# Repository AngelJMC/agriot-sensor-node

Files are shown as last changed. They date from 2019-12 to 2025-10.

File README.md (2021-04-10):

# AGRIOT LoraWAN sensor node




The aim of this project is to provide an Open Source hardware/software platform for the rapid and low-cost development of LoRaWAN sensor nodes. It consists of an [Arduino Pro Mini][4] module, a LoRa [RMF95W][5] communications module, a Buck DC-DC converter and a few components to simplify connection to different sensors.

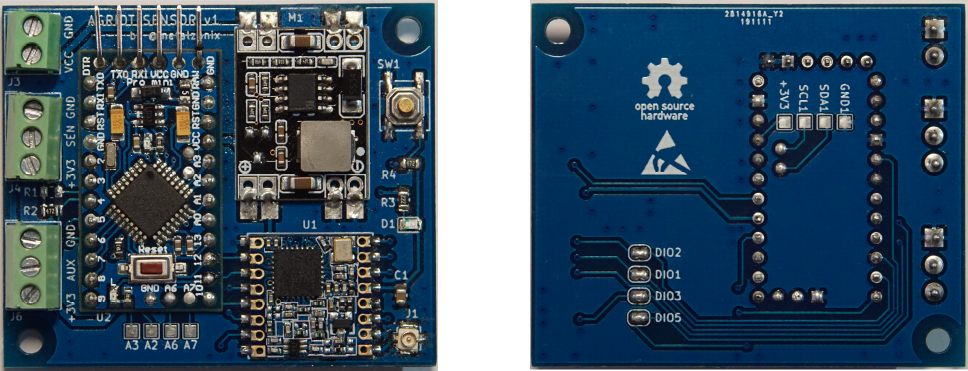
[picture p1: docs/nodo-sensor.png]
MarineGEO circle logo


## Table of contents
- [AGRIOT LoraWAN sensor Node](#agriot-lorawan-sensor-node)
  - [General info](#general-info)
  - [Table of contents](#table-of-contents)
  - [Features](#features)
    - [Hardware](#hardware)
    - [LoRaWAN Features](#lorawan-features)
    - [List of supported sensors](#list-of-supported-sensors)
  - [Get the source code](#get-the-source-code)
    - [Directory Structure](#directory-structure)
  - [Firmware](#firmware)
    - [How to add new sensor support](#how-to-add-new-sensor-support)
  - [Command Line Interface](#command-line-interface)
    - [Commands](#commands)
  - [Connect your Device to LoRaWAN - The Things Network.](#connect-your-device-to-lorawan---the-things-network)
    - [Get your Device EUI](#get-your-device-eui)
    - [Activate your Device](#activate-your-device)
  - [Hardware](#hardware-1)
    - [PCB BOM](#pcb-bom)
  - [Node Examples](#node-examples)

## Features
### Hardware
 * 5-24v Power supply through a screw terminal block.
 * 2 GPIOS accessible from screw terminal blocks, one of them with interrupt.
 * 1 IC2 interface in the botton layer, with soldering pad.
 * 4 Analog inputs in the top layer, with soldering pad.
 * A switch to force the sending of LoRaWAN messages.
### LoRaWAN Features
* [OTAA activation][7]. It is not necessary to add the OTAA activation keys in the code. They are stored in the EEPROM and the configuration is done from the serial port. 
* [Adaptative Data Rate][6] according to the SNR of periodical downlink messages.
* Using [Arduino-LMIC lowpower library][8], a modified version of Arduino-LMIC to work with the low-power modes of the Atmega328P microcontroller.
### List of supported sensors
* DHT series of low-cost temperature/humidity sensors.
* DS18S20, DS18B20, DS1822 temperature sensor.
* GPS with NMEA Standar.
* ADC121 Analog-to-digital converter with I2C interface.
    
## Get the source code
Download repository and update submodules:

```
$ git clone https://github.com/AngelJMC/agriot-sensor-node.git
$ cd agriot-sensor-node
$ git submodule update --init --recursive
```

### Directory Structure

    .
    ├── docs          # Documentation files
    ├── firmware      # FW source code (Visual Studio Code)
    ├── hardware      # HW design files (Kicad)

## Firmware
If you want to modify the source code or program your devices, it is highly recommended to use [Visual Studio Code][2] and the [Platformio][3] plugin. Just open the "firmware" directory with Visual Studio Code and the whole project will be ready for use.
### How to add new sensor support

You must create a new .cpp file in which you implement the communication routines with the sensor. If you use the following scheme you will only have to add the communication with the sensor.  The sensors_update() function is executed periodically and once the sensor acquisition is finished the data is sent by the LoRaWAN communication layer.

~~~
#ifdef SENS_SENSORNAME
#include "protocol.h"
#include "sensors.h"
#include <CayenneLPP.h>

/* Schedule sensore measurement every this senconds */
#define SENSOR_INTERVAL (5*60) //seconds

static osjob_t sensjob;
CayenneLPP lpp(51);

static void sensors_update( osjob_t* j ) {
    os_avoidSleep();

    /*TO-BE Implemented -- Read sensor*/
    float t = readYourSensor();

    /* Update Data Frame using Cayennne Library */
    lpp.reset();
    lpp.addTemperature(1, t); /*Change according your sensor*/
    protocol_updateDataFrame( lpp.getBuffer(), lpp.getSize() );

    /* Schedule next sensor reading*/
    os_setTimedCallback( &sensjob, os_getTime() + sec2osticks(SENSOR_INTERVAL), sensors_update );
    Serial.flush();
    os_acceptSleep();
}

void sensors_init( ) {

    /*TO-BE Implemented -- Init sensor*/
    initYourSensor();

    /*Schedule the first sensor reading*/
    os_setTimedCallback(&sensjob, os_getTime() + sec2osticks(10), sensors_update);
}

#endif

~~~

To compile the code for this new sensor, you will have to add to the platformio.ini configuration file a new [build environment][1].

~~~
[env:pro8MHzatmega328_SENSORNAME]
platform = atmelavr
board = pro8MHzatmega328
framework = arduino
build_flags = -DSENS_SENSORNAME
~~~

Now you will be able to select the build environment from the Visual Studio Code.

## Command Line Interface

The device configuration is done through the command line interface (CLI) implemented in the device.

First, connect your device to the Arduino Serial Monitor over USB. Since the Arduino Pro Mini does not have an on-board FTDI chip, you will need to use a USB-TTL adapter. Set the baud rate to 9600 and open the serial port to establish connection. IMPORTANT: To reduce the device power consumption, the serial interface is only available for 10 minutes after the device power-up.

### Commands

Command ID| Type   | Description 
:--------:|--------|:----------
  D       | R      |  DEVEUI -  Unique device identifier.
  E       | R/W    |  APPEUI -  Unique identifier of the application.    
  K       | R/W    |  APPKEY -  Used in OTAA to generate session keys. 

## Connect your Device to LoRaWAN - The Things Network.

To use the default Over The Air Activation (OTAA) you will need to register your device with its Device EUI

### Get your Device EUI

The Device EUI is a unique address provided by the Atmega328P microcontroller. To retrieve this, type in the serial console:

> D    

Go to The Things Network and open the application to which you wish to add a device and click register device.
        
  * For Device ID, choose a - for this application - unique ID of lower case, alphanumeric characters and nonconsecutive - and _.
  * For Device EUI, copy-paste the one you retrieved from your device.
  * Leave the App Key to be generated.
  * For App EUI, select the generated EUI from the list.

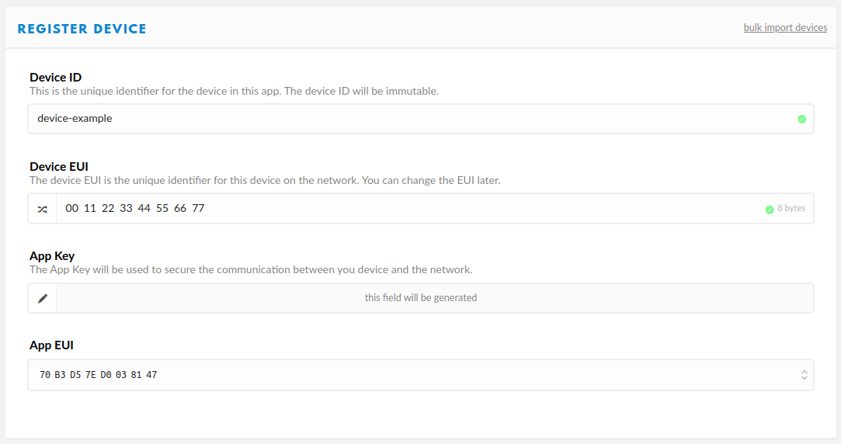
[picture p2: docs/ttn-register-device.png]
TTN Register Device


### Activate your Device

Now that we have registered the device, we can activate the connection from our device itself. Activation means that the device will use the generated App Key to negotiate session keys for further communication. 

Go to Device Overview and copy the 8-byte Application EUI. Now, you have to send the "E" command with the value obtained through the serial port of the device:

> E:70B3D57ED0038147

Repeat the same process to send the 16 byte Application key:

> K:7B4F7BC85D064898DB39214D7607440E

Now, restart the device and it will automatically register to the network.

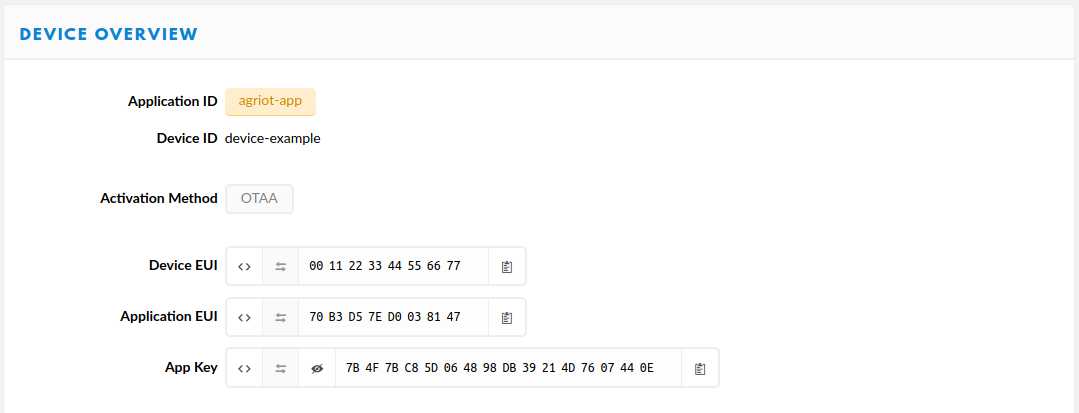
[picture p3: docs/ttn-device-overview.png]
TTN Device Overview


Session keys are not stored in non-volatile memory so they are renegotiated each time the device is powered on. This behavior is not the most appropriate, and will be reviewed in future versions.

## Hardware

Getting the gerbers for PCB fabrication [here]([hardware/gerbers](https://github.com/AngelJMC/agriot-sensor-node/tree/master/hardware/gerbers)).

### PCB BOM

| Name  | Anmount | Description |
| --- | --- | --- |
| [Arduino Pro Mini][20] | 1  | Pro Mini Armega328P 3,3V 8MHz|
| [RFM95W][21] | 1  | RFM95W 868-915MHz LoRa SX1276 transceiver |
| [DC-DC Buck][22] | 1  | 3.3V Fixed output, Input 5v-24v |
| Resistor 2.2k | 1  | 2.2K SMD resistor 0805|
| Resistor 4.7k | 3  | 4.7K SMD resistor 0805|
| Capacitor 4.7 uF/6.3 v | 1  | 4.7 uF SMD capacitor 0805 |
| SMD LED | 1  | LED SMD 0850 |
| [Switch DIP][3] | 1  | Switch 4 PIN Metal SMD  |
| [Screw Terminal 01x03][24] | 2  | 3P - Pitch 3.5/3.96mm Screw PCB Terminal Block Connector |
| [Screw Terminal 01x02][24] | 1  | 2P - Pitch 3.5/3.96mm Screw PCB Terminal Block Connector |
| [Connector U.FL-R-SMT ][25] | 1  |  Connector U.FL-R-SMT |
| [Antenna 3dbi RP-SMA][26] | 1  |  Antenna 3dbi RP-SMA Connector + 21cm SMA Male/u.FL Pigtail Cable |

[20]:https://es.aliexpress.com/item/32341751484.html?spm=a2g0s.9042311.0.0.274263c0KXTWNh
[21]:https://es.aliexpress.com/item/32811523237.html?spm=a2g0s.9042311.0.0.274263c0h3imgq
[22]:https://es.aliexpress.com/item/32742116421.html?spm=a2g0s.9042311.0.0.274263c0h3imgq
[23]:https://www.aliexpress.com/item/32989610390.html?spm=a2g0s.9042311.0.0.274263c02c3pDo
[24]:https://es.aliexpress.com/item/32868442939.html?spm=a2g0s.9042311.0.0.274263c0HmLjas
[25]:https://es.aliexpress.com/item/32833564737.html?spm=a2g0s.9042311.0.0.274263c0HmLjas
[26]:https://www.aliexpress.com/item/32977287261.html?spm=a2g0s.9042311.0.0.274263c0KXTWNh

## Node Examples
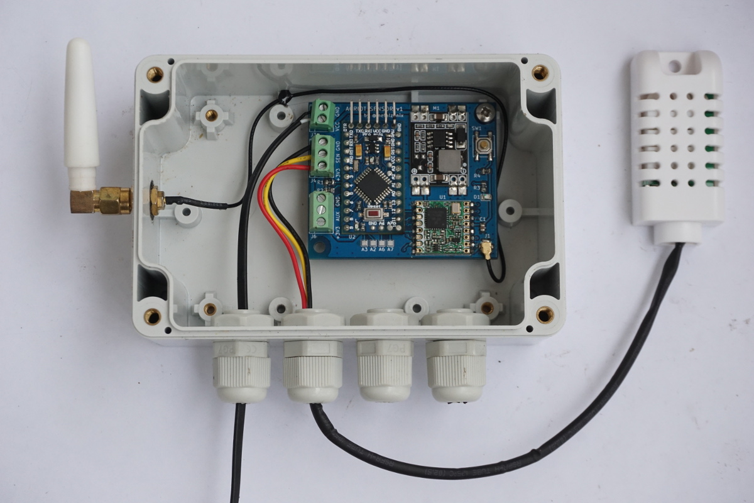
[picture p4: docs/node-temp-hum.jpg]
Sensor node example

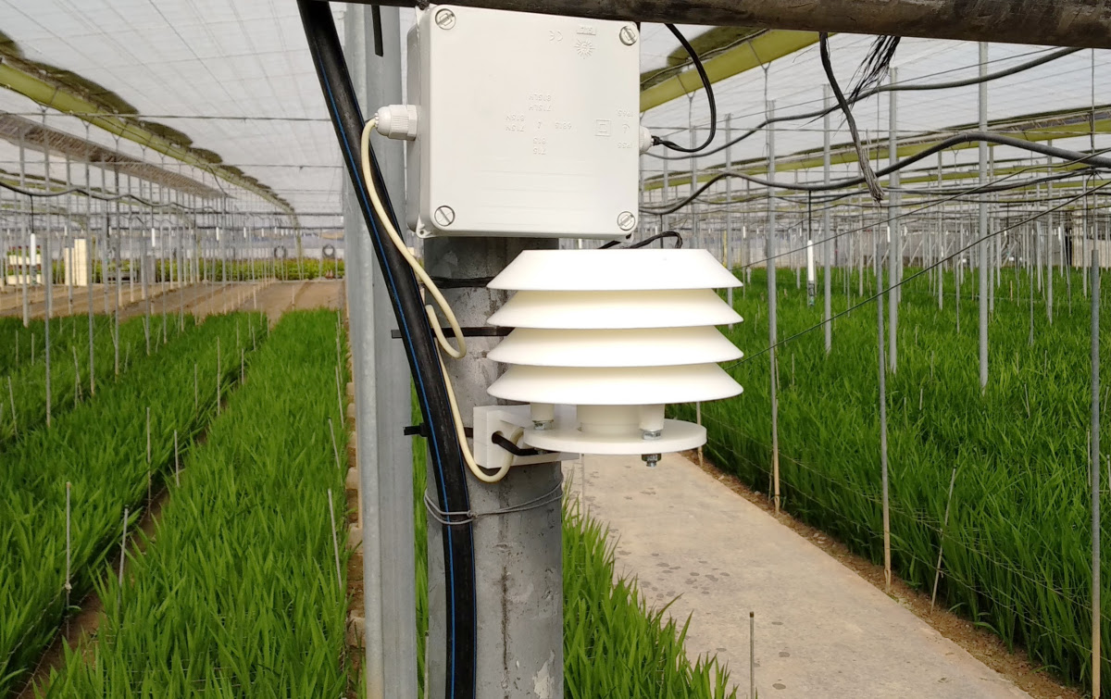
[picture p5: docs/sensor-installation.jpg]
Sensor Installation


[1]: https://docs.platformio.org/en/latest/projectconf/section_env.html
[2]: https://code.visualstudio.com/
[3]: https://platformio.org/
[4]:https://learn.sparkfun.com/tutorials/using-the-arduino-pro-mini-33v/all.pdf
[5]:http://www.anarduino.com/docs/RFM95_96_97_98W.pdf
[6]:https://www.thethingsnetwork.org/docs/lorawan/adaptive-data-rate.html
[7]:https://www.thethingsnetwork.org/docs/devices/registration.html
[8]:https://github.com/AngelJMC/arduino-lmic-lowpower

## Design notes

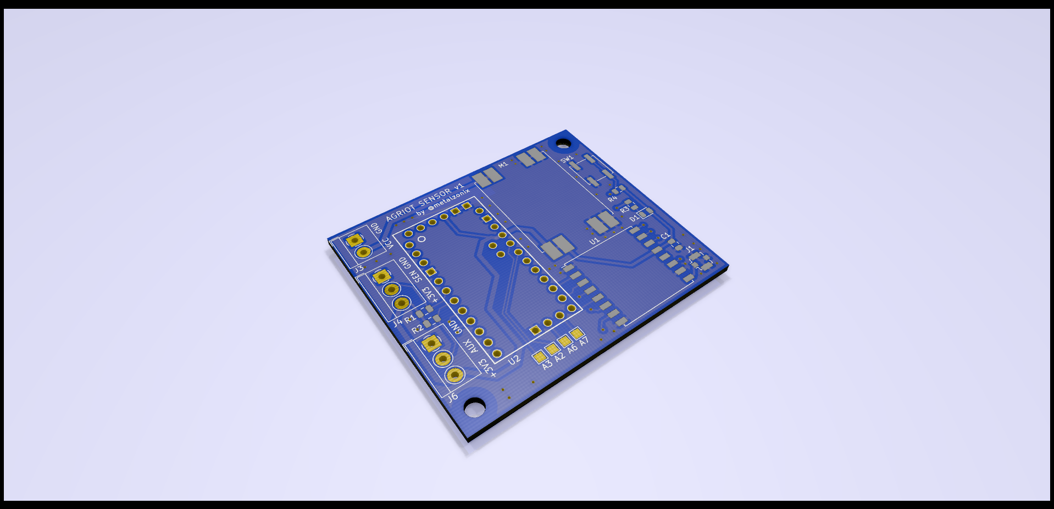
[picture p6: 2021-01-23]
docs/agriot-sensor.png

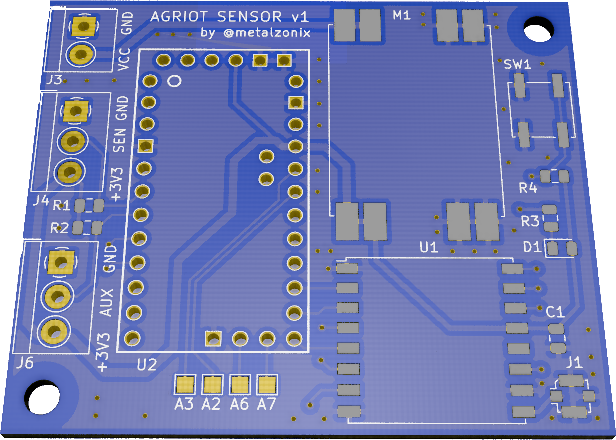
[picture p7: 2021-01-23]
docs/node-render.png

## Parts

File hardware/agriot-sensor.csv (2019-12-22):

Id | Designator | Package | Quantity | Designation | Supplier and ref
1 | REF** | ESD-Logo_6.6x6mm_SilkScreen | 1 | ESD-Logo_6.6x6mm_SilkScreen
2 | REF** | OSHW-Logo_7.5x8mm_SilkScreen | 1 | OSHW-Logo_7.5x8mm_SilkScreen
3 | H2,H1 | MountingHole_2mm | 2 | MountingHole
4 | D1 | LED_0805_2012Metric | 1 | LED
5 | M1 | DC-DC_Buck_Step_Module | 1 | DC-DC_Buck_Step_Module
6 | A7,GND1 | TestPoint_Pad_1.5x1.5mm | 2 | GND
7 | A6,SDA1 | TestPoint_Pad_1.5x1.5mm | 2 | SDA
8 | A3,SCL1 | TestPoint_Pad_1.5x1.5mm | 2 | SCL
9 | A2,+3V3 | TestPoint_Pad_1.5x1.5mm | 2 | +3v3
10 | R3 | R_0805_2012Metric | 1 | 2.2kR
11 | SW1 | SW_Push_1P1T_NO_CK_KSC6xxJ | 1 | SW_DIP_x01
12 | R4,R2,R1 | R_0805_2012Metric | 3 | 4.7k
13 | J6,J4 | TerminalBlock_4Ucon_1x03_P3.50mm_Horizontal | 2 | Screw_Terminal_01x03
14 | J3 | TerminalBlock_4Ucon_1x02_P3.50mm_Horizontal | 1 | Screw_Terminal_01x02
15 | U2 | ARDUINO_Pro-MiniALLB_Aliexpress | 1 | ARDUINO_Pro-MiniALL
16 | DIO2,DIO3,DIO5,DIO1 | SolderJumper-2_P1.3mm_Open_RoundedPad1.0x1.5mm | 4 | SolderJumper_2_Open
17 | J1 | U.FL_Molex_MCRF_73412-0110_Vertical | 1 | Conn_Coaxial
18 | U1 | HOPERF_RFM9XW_SMD | 1 | RFM95W-868S2
19 | C1 | C_0805_2012Metric | 1 | 4.7uF/6.3v

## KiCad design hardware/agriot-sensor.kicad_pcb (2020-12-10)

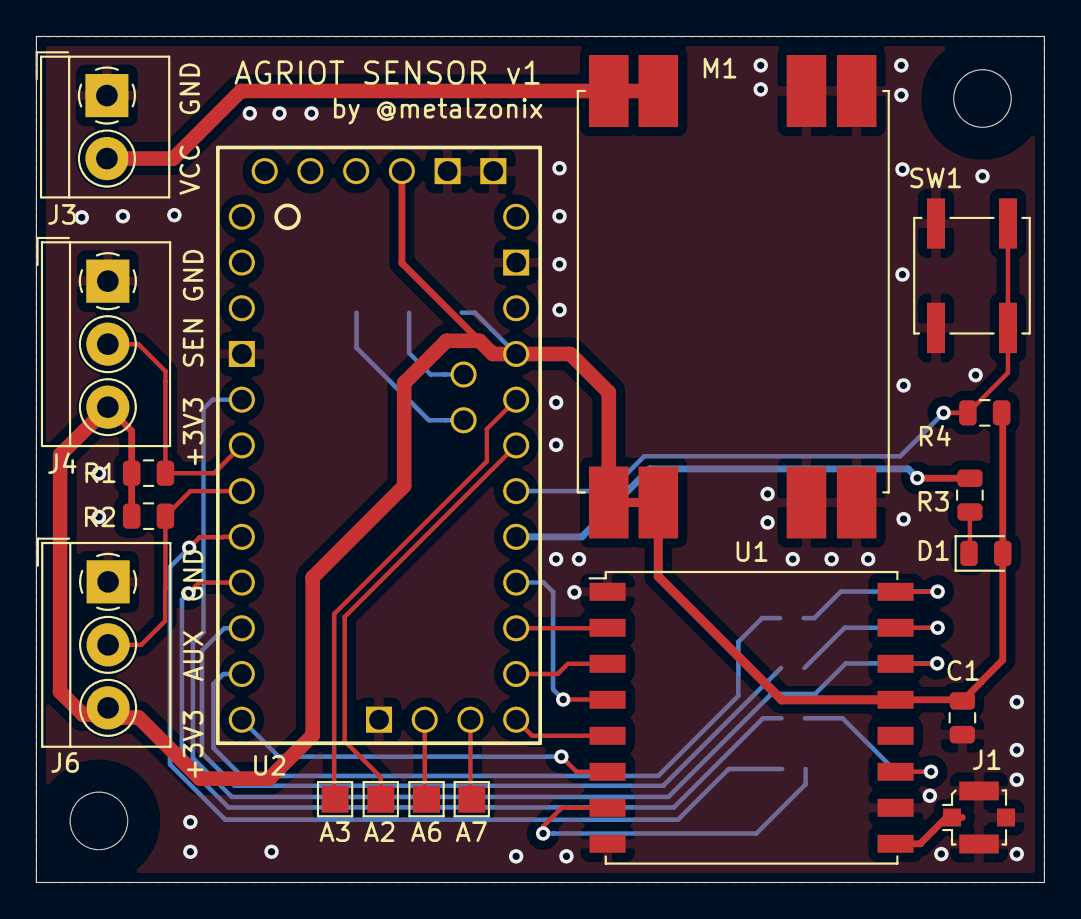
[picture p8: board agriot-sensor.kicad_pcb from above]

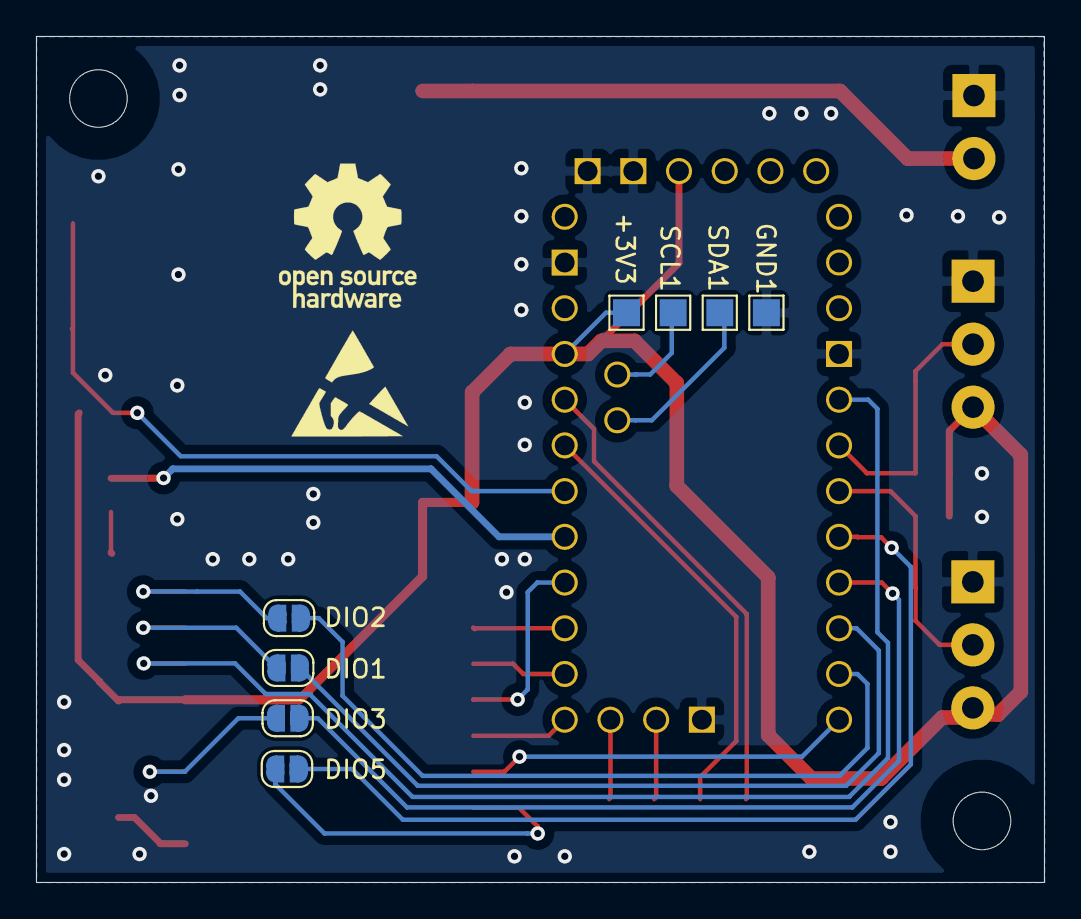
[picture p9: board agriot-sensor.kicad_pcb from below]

Board: 2 copper layers, 56.0 x 47.0 mm, 28 parts (8 on the bottom side), 29 nets.

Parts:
+3V3: +3v3; TestPoint_Pad_1.5x1.5mm
A2: +3v3; TestPoint_Pad_1.5x1.5mm
A3: SCL; TestPoint_Pad_1.5x1.5mm
A6: SDA; TestPoint_Pad_1.5x1.5mm
A7: GND; TestPoint_Pad_1.5x1.5mm
C1: 4.7uF/6.3v; C_0805_2012Metric
D1: LED; LED_0805_2012Metric
DIO1, DIO2, DIO3, DIO5: SolderJumper_2_Open; SolderJumper-2_P1.3mm_Open_RoundedPad1.0x1.5mm
GND1: GND; TestPoint_Pad_1.5x1.5mm
H1, H2: MountingHole; MountingHole_3.2mm_M3
J1: Conn_Coaxial; U.FL_Molex_MCRF_73412-0110_Vertical
J3: Screw_Terminal_01x02; TerminalBlock_4Ucon_1x02_P3.50mm_Horizontal
J4, J6: Screw_Terminal_01x03; TerminalBlock_4Ucon_1x03_P3.50mm_Horizontal
M1: DC-DC_Buck_Step_Module
R1, R2, R4: 4.7k; R_0805_2012Metric
R3: 2.2kR; R_0805_2012Metric
SCL1: SCL; TestPoint_Pad_1.5x1.5mm
SDA1: SDA; TestPoint_Pad_1.5x1.5mm
SW1: SW_DIP_x01; SW_Push_1P1T_NO_CK_KSC6xxJ
U1: RFM95W-868S2; HOPERF_RFM9XW_SMD
U2: ARDUINO_Pro-MiniALL; ARDUINO_Pro-MiniALLB_Aliexpress

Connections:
+3V3: +3V3.1, C1.2, D1.2, J4.3, J6.3, M1.2, R1.1, R2.1, R4.1, U1.13, U2.21, U2.PRG4
+12V: J3.2, M1.1
A2: A2.1, U2.19
A3: A3.1, U2.20
A6: A6.1, U2.A6
A7: A7.1, U2.A7
GND: C1.1, GND1.1, J1.2, J3.1, J4.1, J6.1, M1.3, SW1.2, U1.1, U1.8, U1.10, U2.4, U2.23, U2.25, U2.PRG5, U2.PRG6
I2C_SCL: SCL1.1, U2.A5
I2C_SDA: SDA1.1, U2.A4
LED: R3.2, U2.17
unnamed: D1.1, R3.1
unnamed: DIO1.1, U1.15
unnamed: DIO2.1, U1.16
unnamed: DIO3.1, U1.11
unnamed: DIO5.1, U1.7
unnamed: J1.1, U1.9
RFM95_DIO0: U1.14, U2.5
RFM95_DIO1: DIO1.2, U2.10
RFM95_DIO2: DIO2.2, U2.11
RFM95_DIO3: DIO3.2, U2.9
RFM95_DIO5: DIO5.2, U2.8
RFM95_NSS: U1.5, U2.13
RFM95_RST: U1.6, U2.12
SENSOR_AUX: J6.2, R2.2, U2.7
SENSOR_DATA: J4.2, R1.2, U2.6
SPI_MISO: U1.2, U2.15
SPI_MOSI: U1.3, U2.14
SPI_SCK: U1.4, U2.16
SWITCH_CFG: R4.2, SW1.1, U2.18

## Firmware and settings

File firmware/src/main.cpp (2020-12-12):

/*
    Project: <https://github.com/AngelJMC/agriot-sensor-node>   
    Copyright (c) 2020 Angel Maldonado <angelgesus@gmail.com>. 
    Licensed under the MIT License: <http://opensource.org/licenses/MIT>.
    SPDX-License-Identifier: MIT 
*/

#include "Arduino.h"
#include "cfg.h"
#include "cli.h"
#include "protocol.h"
#include "sensors.h"
#include "lmic.h"


void setup() {
  
    Serial.begin(9600);
    Serial.println(F("Starting"));

    param_load(  );
    
    os_init();
    protocol_init();
    cli_init();
    sensors_init();

}


void loop() {
    os_runloop_once( ); 
    protocol_checkSwitch( );
}

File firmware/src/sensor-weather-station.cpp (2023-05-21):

/*
    Sensors:
      Air temperature and Humidity: DHT22 connected to GPIO 3
      Soil moisture: analog sensor conneted to ADC121 (i2c port)
      Soil temperature: DS18B20 connected to GPIO 4
    Project: <https://github.com/AngelJMC/agriot-sensor-node>   
    Copyright (c) 2020 Angel Maldonado <angelgesus@gmail.com>. 
    Licensed under the MIT License: <http://opensource.org/licenses/MIT>.
    SPDX-License-Identifier: MIT 
*/

#ifdef SENS_WEATHER_STATION
#include "protocol.h"
#include "sensors.h"
#include <OneWire.h>
#include <Wire.h>
#include "DHT_U.h"
#include <CayenneLPP.h>

//Schedule sensore measurement every this senconds
#define SENSOR_INTERVAL (5*60)//seconds

enum {
    REG_ADDR_RESULT   = 0x00,
    REG_ADDR_ALERT    = 0x01,
    REG_ADDR_CONFIG   = 0x02,
    REG_ADDR_LIMITL   = 0x03,
    REG_ADDR_LIMITH   = 0x04,
    REG_ADDR_HYST     = 0x05,
    REG_ADDR_CONVL    = 0x06,
    REG_ADDR_CONVH    = 0x07,

    ADDR_ADC121       = 0x54,
};

static unsigned int adcval;   

struct dssens {
  byte type_s;
  byte data[12];
  byte addr[8];
};

enum { 
    DHT22_PIN = 3,
    DS_PIN = 4
};

static osjob_t sensjob;
static dssens sensor;
CayenneLPP lpp(51);
OneWire  ds( DS_PIN );  // on pin 10 (a 4.7K resistor is necessary)
DHT dht( DHT22_PIN, DHT22 ); 

static double mapf(double val, double in_min, double in_max, double out_min, double out_max) {
    
    val = val < in_min ? in_min : val;
    val = val > in_max ? in_max : val;
    return (val - in_min) * (out_max - out_min) / (in_max - in_min) + out_min;
}


static float ds_readTemperature( struct dssens* ds_hdl ) {
    ds.reset();
    ds.select( ds_hdl->addr );
    ds.write(0x44, 1);        // start conversion, with parasite power on at the end

    ds.reset();
    ds.select( ds_hdl->addr );    
    ds.write( 0xBE );         // Read Scratchpad

    for ( byte i = 0; i < 9; i++) {           // we need 9 bytes
      ds_hdl->data[i] = ds.read();
    }

    // Convert the data to actual temperature
    // because the result is a 16 bit signed integer, it should
    // be stored to an "int16_t" type, which is always 16 bits
    // even when compiled on a 32 bit processor.
    int16_t raw = ( ds_hdl->data[1] << 8) | ds_hdl->data[0];
    if ( ds_hdl->type_s ) {
      raw = raw << 3; // 9 bit resolution default
      if ( ds_hdl->data[7] == 0x10 ) {
        // "count remain" gives full 12 bit resolution
        raw = (raw & 0xFFF0) + 12 - ds_hdl->data[6];
      }
    } else {
      byte cfg = ( ds_hdl->data[4] & 0x60 );
      // at lower res, the low bits are undefined, so let's zero them
      if (cfg == 0x00) raw = raw & ~7;  // 9 bit resolution, 93.75 ms
      else if (cfg == 0x20) raw = raw & ~3; // 10 bit res, 187.5 ms
      else if (cfg == 0x40) raw = raw & ~1; // 11 bit res, 375 ms
      //// default is 12 bit resolution, 750 ms conversion time
    }
    return (float)raw / 16.0;
}

static uint16_t readMoisture( void ) {

    Wire.beginTransmission( ADDR_ADC121 );        // transmit to device
    Wire.write( REG_ADDR_RESULT );                // get reuslt
    Wire.endTransmission();

    Wire.requestFrom( ADDR_ADC121, 2 );           // request 2byte from device
    if( Wire.available() == 2 ) {
        adcval = (Wire.read()&0x0f)<<8;
        adcval |= Wire.read();
    }
    return adcval;
}
static void sensors_update( osjob_t* j ) {

    os_avoidSleep();
    float t_soil = ds_readTemperature( &sensor );
    float h = readMoisture( )/100.0;
    float h_soil = mapf( adcval, 1580, 2600, 100.0, 0.0);
    float t_air = dht.readTemperature( ); // Read temperature as Celsius
    float h_air = dht.readHumidity( );
    SENSORS_PRINT_F("Soil: ");  SENSORS_PRINT(t_soil); SENSORS_PRINT_F(" *C, "); SENSORS_PRINTLN(h_soil); SENSORS_PRINT_F(" *%\t\n");
    SENSORS_PRINT_F("Air: "); SENSORS_PRINT(t_air); SENSORS_PRINT_F(" *C, ");   SENSORS_PRINT(h_air); SENSORS_PRINT_F(" %\t\n");
    
    /* Update Data Frame to Send */
    lpp.reset();
    lpp.addTemperature(1, t_soil);
    lpp.addAnalogInput(1, h);
    lpp.addAnalogInput(2, h_soil);
    lpp.addTemperature(2, t_air);
    lpp.addRelativeHumidity(1, h_air);

    protocol_updateDataFrame( lpp.getBuffer(), lpp.getSize() );

    os_setTimedCallback( &sensjob, os_getTime() + sec2osticks(SENSOR_INTERVAL), sensors_update );
    Serial.flush();
    os_acceptSleep();
}

void sensors_init( ) {

    if ( !ds.search(sensor.addr)) {
        ds.reset_search();
        delay(250);
        return;
    }
    
    if (OneWire::crc8(sensor.addr, 7) != sensor.addr[7]) {
        SENSORS_PRINT_F("CRC is not valid!\n");
        return;
    }
  
    // the first ROM byte indicates which chip
    switch (sensor.addr[0]) {
      case 0x10:
        SENSORS_PRINT_F("DS18S20\n");  // or old DS1820
        sensor.type_s = 1;
        break;
      case 0x28:
        SENSORS_PRINT_F("DS18B20\n");
        sensor.type_s = 0;
        break;
      case 0x22:
        SENSORS_PRINT_F("DS1822\n");
        sensor.type_s = 0;
        break;
      default:
        SENSORS_PRINT_F("Device is not a DS18x20.\n");
        return;
    }

    /*Init ADC121 - Soil moisture sensor*/
    Wire.begin();
    Wire.beginTransmission( ADDR_ADC121 );        // transmit to device
    Wire.write( REG_ADDR_CONFIG );                // Configuration Register
    Wire.write( 0x02 );  //0x20  //0x10 works
    Wire.endTransmission(); 

    /*Init DHT22 sensor*/
    dht.begin();

    /* Schedule the first sensor reading*/
    os_setTimedCallback(&sensjob, os_getTime() + sec2osticks(10), sensors_update);
}

#endif

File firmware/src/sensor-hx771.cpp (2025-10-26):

/*
    Project: <https://github.com/AngelJMC/agriot-sensor-node>   
    Copyright (c) 2020 Angel Maldonado <angelgesus@gmail.com>. 
    Licensed under the MIT License: <http://opensource.org/licenses/MIT>.
    SPDX-License-Identifier: MIT 
*/

#ifdef SENS_HX771
#include "protocol.h"
#include "DHT_U.h"

#include "HX711.h"
#include "sensors.h"
#include <CayenneLPP.h>

//Schedule sensore measurement every this senconds
#define SENSOR_INTERVAL (2.5*60)//seconds

static osjob_t sensjob;
CayenneLPP lpp(51);

// HX711 circuit wiring
const int LOADCELL_DOUT_PIN = A4;
const int LOADCELL_SCK_PIN = A5;

DHT dht( 4, DHT22 ); 

HX711 scale;

static void sensors_update( osjob_t* j ) {
    os_avoidSleep();
    long reading = 0;
    if (scale.wait_ready_timeout(1000)) {
        reading = scale.read();
        Serial.print("HX711 reading: ");
        Serial.println(reading);
    } else {
        Serial.println("HX711 not found.");
    }
    
    float t = dht.readTemperature( ); // Read temperature as Celsius
    float h = dht.readHumidity( );

    float value = reading /10000.0;
    SENSORS_PRINT_F("Value: "); SENSORS_PRINT(value); SENSORS_PRINT_F(" ");
    SENSORS_PRINT_F("Temperature: "); SENSORS_PRINT(t); SENSORS_PRINT_F(" *C ");
    SENSORS_PRINT_F("Humidity: ");    SENSORS_PRINT(h); SENSORS_PRINT_F(" %\t\n");
    
    /* Update Data Frame to Send */
    lpp.reset();
    lpp.addTemperature(1, t);
    lpp.addRelativeHumidity(2, h);
    lpp.addAnalogInput(3, value);
    protocol_updateDataFrame( lpp.getBuffer(), lpp.getSize() );
    /* Schedule next sensor reading */
    os_setTimedCallback( &sensjob, os_getTime() + sec2osticks(SENSOR_INTERVAL), sensors_update );
    Serial.flush();
    os_acceptSleep();
}

void sensors_init( ) {

    scale.begin(LOADCELL_DOUT_PIN, LOADCELL_SCK_PIN);
    dht.begin();
    delay(1000);
    /* Schedule the first sensor reading*/
    os_setTimedCallback(&sensjob, os_getTime() + sec2osticks(10), sensors_update);
}

#endif

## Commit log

2019-12-22 Add all hardware design file for Kicad
    [LoRaModule.csv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]
2019-12-24 Work around main.cpp. Add support for DHT22 and DS18B20 sensors.
2020-03-03 Add new macros to selec sensor type, tx interval and sampling time.
2020-08-19 Bug fixing and other minors changes
    [ds.cpp, main.cpp, protocol.cpp]
2020-09-26 Change Activation by Personalization(ABP) to Over-the-Air Activation (OTAA)
    Over-the-Air Activation (OTAA) is the preferred and most secure way to
    connect with The Things Network. Devices perform a join-procedure with
    the network, during which a dynamic DevAddr is assigned and security
    keys are negotiated with the device.
2020-09-26 Add support for the TM5 Moisture - Temperature Sensor
2020-11-02 Add new sensor support, ADC121 driver to read the Capative Soil Moisture analog sensor
2020-11-02 Update the hardware design files
    [LoRaModule.sch]
2020-11-08 Use Adaptative Data Rate (ADR), fix bug with the lmic library when use this feature.
    [protocol.cpp, sensor-adc121.cpp]
2020-11-24 Bug fixing related to last changes in command line interface.
    [cli.cpp, sensor-adc121.cpp]
2020-11-28 Improvements to reduce power requirements. When the cpu is idle waiting for the execution of the next job, it is put in power-down mode. - Modified lmic layer. - Usage of low-power library.
2020-11-29 Update hardware schematic
    [LoRaModule.sch]
2020-12-09 The reading of the sensors and data sending have been synchronized.
2020-12-10 Update hardware files
    [agriot-sensor.csv, agriot-sensor.kicad_pcb, agriot-sensor.sch]
2020-12-10 Add the project kicad libraries to repository
2020-12-10 Update kicad project files
    [agriot-sensor.kicad_pcb, agriot-sensor.sch]
2020-12-10 Remove unused kicad files.
2021-04-10 Added new build flavour TEMP_MOISTURE
    Implements temperature and soil moisture probe readout
2023-05-21 Added weather station device: Air Temperature and Humidity + Soil temp + Soil moisture
2025-10-26 Added support for HX711, a precision 24-bit analog-to-digital converter (ADC) designed for weigh scales
